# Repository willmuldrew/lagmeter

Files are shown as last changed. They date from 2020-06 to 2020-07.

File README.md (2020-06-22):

Lagmeter
--------

The hardware works by itself and measure total display lag from a simulated HID event to a dark to/from light transition on the screen.  Results are displayed on OLED screen.  The USB bus is pretty fast - events reach your app in ~1-2 ms.  The same cannot be said of all real keyboards which can add 10s of ms through a combination of slow matrix scanning/embedded CPU and slow USB bus polling speeds.

Different test modes can be selected by holding down the button to cycle through keypress (x), alt-tab, alt-esc, mouse click etc...

Optionally, you can run some software on the target machine to collect more data:
 * lagcap.py - captures packets on an interface and pulls light sensor results from arduino. Writes both into csvs in your temp dir.  Syncs clock with device
 * LagWinApp.exe - very minimal windows app that cycles from black-white-black with keypresses (x).  Also logs timestamped WM_PAINT, WM_KEYDOWN events to the tempdir
 * ProcessResults.ipynb jupyter notebook - reads in arduino output, pcap and LagWinApp output from disk and plots some results

Here's some of the charts that the notebook produces showing network traffic for an RDP test.  At the top you see the changing brightness of the screen for a letter X as read by the arduino.  Below you see the network traffic - I can only assume it is the outbound key press and display update coming back - it's all encrypted so you can't really be sure!

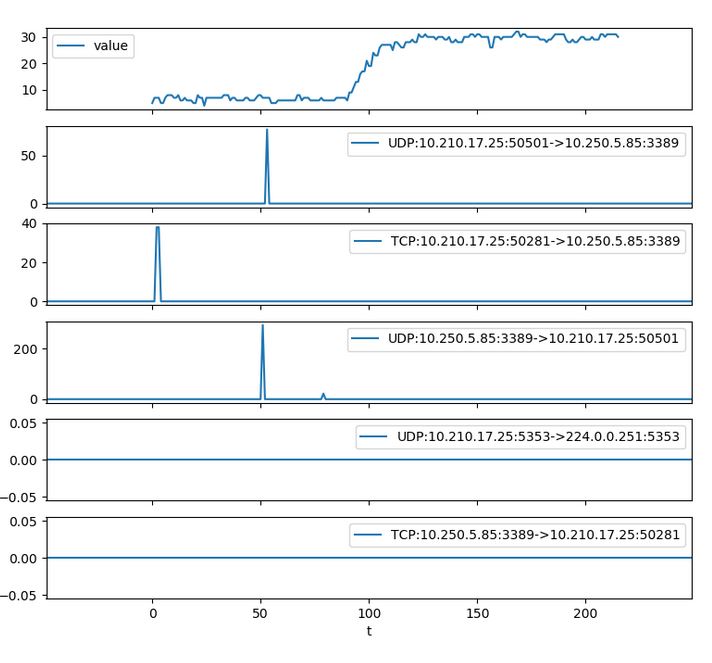
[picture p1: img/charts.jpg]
chart


Getting started
---------------

1. Upload arduino sketch to your Leonardo (or clone)
1. Run lagcap.py locally in a command prompt (e.g. I use a anaconda prompt in a conda environment 
with the relevant deps - pyshark, pyserial, pandas)  Strangely, no admin prompt required despite serial and pcaps
1. Point sensor somewhere on the screen (e.g. just past the cursor on a text prompt - will depend on the selected mode)
1. Hit button
1. Results are written to tmp dir and can be viewed with the ProcessResults jupyter notebook

Building LagWinApp
------------------

If you want a really minimal baseline app you can build and run LagWinApp and use that as your test target. It will drop some timestamped window message logs in the temp dir which can be plotted against other data.

I've build this with Visual Studio 2019 - you can download the community edition for free from MS.

Python Dependencies
------------

pyshark, pyserial and pandas

Hardware
--------

Here's my meter:

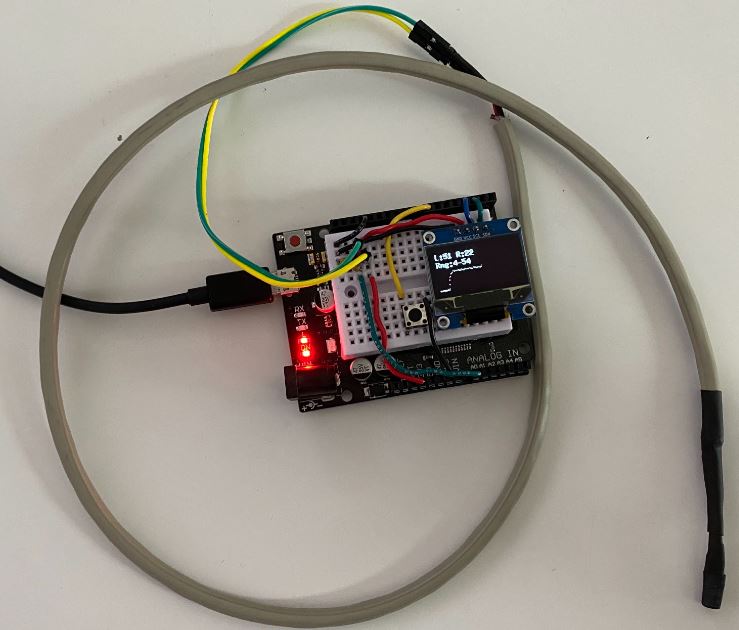
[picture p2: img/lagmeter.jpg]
meter


And here's the wiring (I hope this is right!)  It's not exactly the same I2C SSD 1306 display I use or phototransistor part, but you get the idea. Some notes:
* Leonardo I2C pins are in a different location from other models - check the data sheets
* Make sure you connect the phototransistor the right way round!

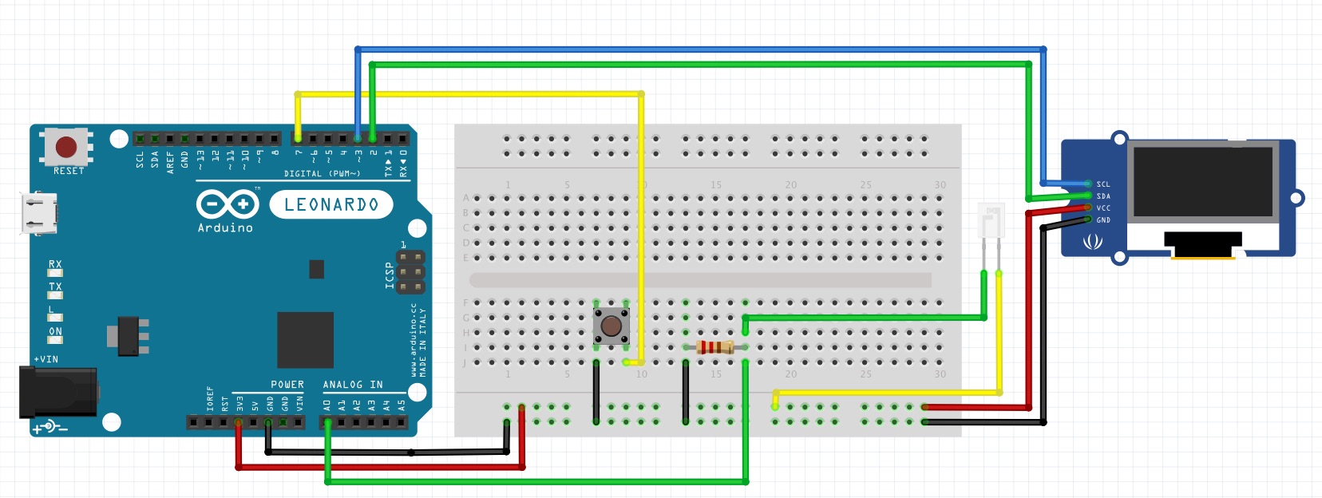
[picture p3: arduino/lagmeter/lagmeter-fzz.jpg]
wiring


Components:
* Arduino Leonard or clone (it's required since it can emulate a USB HID in hardware)
* SSD1306 OLED display - I bought these: https://www.amazon.co.uk/dp/B0832VQN65/ref=pe_3187911_185740111_TE_item
* SFH 3310 phototransistor https://uk.rs-online.com/web/p/phototransistors/6547808/  (I initially used an LDR but it was too slow to react and made it look like the display response time was ~50ms). It's got some heat-shrink round it here for insulation, but also to make a nice window you can point at the screen. Make sure it's wired the right way round!
* momentary microswitch - for initiating captures. Long press to change modes
* resistor 47kohm - this gives us a sensor response time of about 2ms (tested with an led driven by a square wave and an oscilloscope). A smaller resistor means that the capacitance in the sensor drains quicker and response time is faster. However the voltage change shrinks.  2ms seems fine for now, though I might be able to find a better sensor circuit.  I could also use 5v instead of 3.3 (I think), and tweak the software to deal with a lower dynamic range and more noise.
* some wires/cable

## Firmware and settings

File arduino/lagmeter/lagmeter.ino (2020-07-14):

// libs required:
// u8g2 (display)
// AceButton (pushbuttons)


#include <Arduino.h>
#include <Keyboard.h>
#include <Mouse.h>
#include <Wire.h>
#include <U8g2lib.h>
#include <AceButton.h>

using namespace ace_button;

#define SYNC_TIMEOUT_MILLIS 1000

#define SAMPLE_BUFFER_LENGTH 200  // not much memory on arduino!
#define MULTI_RUN_LENGTH 10
#define LED_PIN 13 // going to light this while the capture's active - helpful for debugging and calibration

// OLED display
U8G2_SSD1306_128X64_NONAME_1_HW_I2C u8g2(U8G2_R0, /* reset=*/ U8X8_PIN_NONE);

// Target interval for light capture measurements
const int sampleInterval = 2000; // micros - approx

// How long to busy sample the sensor (then applies mean)
const int sampleDuration = 1000;

typedef struct datapoint {
  uint16_t timestamp;
  uint8_t value;
} datapoint_t;

// Global state for the light-level capture buffer
long t0 = 0;
int writePosition = SAMPLE_BUFFER_LENGTH ;
datapoint_t captureBuffer[SAMPLE_BUFFER_LENGTH];

// OLED display status messages
char msgBufferA[17];
char msgBufferB[17];

AceButton startCaptureButton(7);
AceButton modeButton(6);
AceButton* buttons[] = { 
  &startCaptureButton, 
  &modeButton
};

int runsToDo = 0;
int currentRun = 0;

float multiRunLagSum = 0;
float multiRunLagSumSq = 0;
int multiRunLagCount = 0;


enum class Mode { 
  KeyboardX,
  AltTab,
  LeftClick,
  AltEscape, // AltEscape is next window switching - faster than alt tab (use shift to go back!)
  Count
};

Mode currentMode = Mode::KeyboardX;

void nextMode() {
  currentMode = static_cast<Mode>((static_cast<int>(currentMode) + 1) % static_cast<int>(Mode::Count)); 
  writeScreenMessage("Mode:", getModeDescription(currentMode));
}

const char* getModeDescription(Mode m) {
  switch(m) {
    case Mode::KeyboardX:
      return "Key-X";
    case Mode::AltTab:
      return "Alt-Tab";
    case Mode::LeftClick:
      return "Left Click";    
    case Mode::AltEscape:
      return "Alt-Escape";
  }
}

void handleButtonEvent(AceButton* pButton, uint8_t eventType, uint8_t /*buttonState*/) {
  if(pButton == &startCaptureButton) {
    switch (eventType) {
      case AceButton::kEventClicked:
        startTest(1);
        break;
      case AceButton::kEventLongPressed:
        startTest(MULTI_RUN_LENGTH);
        break;    
    }
  } else if(pButton == &modeButton) {
    switch (eventType) {
       case AceButton::kEventClicked:     
        nextMode();
        break;    
    }
  }
}


void setup() {
  for(auto pButton : buttons) {
    pinMode(pButton->getPin(), INPUT_PULLUP);  
    pButton->setEventHandler(handleButtonEvent);
    ButtonConfig* buttonConfig = pButton->getButtonConfig();
    buttonConfig->setEventHandler(handleButtonEvent);
    buttonConfig->setFeature(ButtonConfig::kFeatureClick);
    buttonConfig->setFeature(ButtonConfig::kFeatureLongPress);
    buttonConfig->setFeature(ButtonConfig::kFeatureSuppressAfterClick);
  }
  
  u8g2.begin();
    
  Serial.begin(115200);  
  Keyboard.begin();
  Mouse.begin();

  clearCaptureBuffer();
  writeScreenMessage("Ready...", "");
  drawScreen();

  pinMode(LED_PIN, OUTPUT);    
  digitalWrite(LED_PIN, LOW);
}

void writeScreenMessage(const char* line1, const char* line2) {
  snprintf(msgBufferA, sizeof(msgBufferA), line1);
  snprintf(msgBufferB, sizeof(msgBufferB), line2);
  drawScreen();   
}

void clearCaptureBuffer() {
   memset(captureBuffer, 0, sizeof(captureBuffer));
}

void drawScreen() {
  u8g2.firstPage();  
  do {
    // Write some messsages
    u8g2.setFont(u8g2_font_7x13B_tf);
    u8g2.drawStr(0,13, msgBufferA);
    u8g2.drawStr(0,26, msgBufferB);

    // Draw a tiny chart
    int nWidth = 72;
    int nHeight = 32;
    int range = 1;

    int minValue = 1024;
    int maxValue = -1;

    for(int n=0;n<SAMPLE_BUFFER_LENGTH;++n) {
      int val = captureBuffer[n].value;
      minValue = min(minValue, val);
      maxValue = max(maxValue, val);
    }    
    
    range = max(maxValue - minValue, 32);        
    for(int x=0;x<nWidth;++x) {
        int nSample = (SAMPLE_BUFFER_LENGTH * x) / nWidth;
        int value = captureBuffer[nSample].value;
        int y = (value - minValue) * 32 / range;
        u8g2.drawPixel(x, 63 - y);
    }
  } while(u8g2.nextPage() );
}


// Read a line from serial up to \n with a timeout
unsigned int serialReadLn(char* buffer, size_t buffLength, int timeoutMillis) {
  unsigned long tStart = millis();  
  unsigned int pos = 0;
  memset(buffer, 0, buffLength);

  while(true) {
    if((millis() - tStart) > timeoutMillis) {
      memset(buffer, 0, buffLength);
      pos = 0;
      break;
    }

    if(Serial.available() > 0) {
      char c = Serial.read();
      if(pos < buffLength) {
        buffer[pos++] = c;
      }
      if(c == '\n') {
        break;
      }    
    }
  }
  return pos;
}

void startCapture() {
  clearCaptureBuffer();
  writePosition = 0; 
  t0 = micros();    
  digitalWrite(LED_PIN, HIGH);
}

// Attempt to sync clock with host on serial bus. Requires relevant lagcap python process to be running
// on the other end...  will wait SYNC_TIMEOUT_MILLIS before giving up to prevent the lack of correct
// host process hanging the arduino
//
// 3 way handshake:
//  * the arduino snaps local micros()
//  * ardunio says SYNC to host
//  * host snaps system time and responds OK
//  * ardunio snaps local micros() again
//  * arduino reports both micros timestamps to host
//
// Host now knows that it's system timestamp lies between the two micros() timestamps.  It can then translate
// ardunio micros() timestamps -> system time with a sub milli accuracy (round-trip is ~0.5ms IIRC)
// 
// Issues:
//  micros() wraps once an hour so could be unlucky... will deal with this at the host end by adding 2**32
//  RTT is variable - could get remote host to respond with AGAIN to retry until a decent RTT is achieved
boolean trySerialClockSync() {
  char strBuffer[64];
  unsigned long localMicrosA = 0;
  unsigned long localMicrosB = 0;

  localMicrosA = micros();
  Serial.print("SYNC\r\n");
  Serial.flush(); 
  
  if(serialReadLn(strBuffer, sizeof(strBuffer), SYNC_TIMEOUT_MILLIS) > 0){      
    if(strcmp(strBuffer, "OK\r\n") == 0) {        
      localMicrosB = micros();
      sprintf(strBuffer, "SYNCED %ld %ld\r\n", localMicrosA, localMicrosB);
      Serial.print(strBuffer);
      Serial.flush();         
      return true;      
    }
  }   
  return false;  
}

boolean isCaptureRunning() {
  return writePosition < SAMPLE_BUFFER_LENGTH;
}

// Take as many readings as possible in the time we're given
int readSmoothedAnalog(int durationMicros){
  unsigned long start = micros();
  unsigned long now = start;
  float sum = 0.0;
  int count = 0;

  // micros() wraps!
  while(now - start < durationMicros && now >= start) {
    sum += analogRead(A0);
    count++;
    now = micros();
  }
  if(count == 0) { 
    // uhoh - either durationMicros was too short, we had a weird hang, or micros wrapped - abort!
    return -1;
  }
  return (int)(sum / count);
}

void startTest(int runs){
  writeScreenMessage("Test", "starting...");  
  if(trySerialClockSync()) {
    delay(1000); // give the remote host a chance to kick off pcaps etc...
  }       

  multiRunLagCount = 0;
  multiRunLagSum = 0;
  multiRunLagSumSq = 0;
  
  runsToDo = runs;
  currentRun = 0;
}

void loop() {  
  if(isCaptureRunning()) {
    // If the capture is running we don't want to do anything else
    unsigned long t = micros();
    int reading = readSmoothedAnalog(sampleDuration);
    if(reading >= 0) {    
      captureBuffer[writePosition].value = reading / 4;
      captureBuffer[writePosition].timestamp = (t - t0) / 1000;
      writePosition++;
    } else {
      // skip - something went a bit wrong!
    }
    
    if(writePosition == SAMPLE_BUFFER_LENGTH) {
      digitalWrite(LED_PIN, LOW); 
      // We've done our last measurement - do some processing for local display and dump results to the 
      // serial port      
      dumpResultsToSerial();
      processResults();
      
      currentRun++;
      if(runsToDo > 1 && currentRun == runsToDo) {
        // We've finished a multirun
        processMultiResults();
      }

      // If we generated a keypress, let's delete it for convenience...  Sometimes it gets annoying though
      // if your backspaces hit a browser!
      doHIDUndo();
      // Update the screen (including drawing a chart)
      drawScreen();      
    } else {
      // busy loop to delay until next sample is scheduled...
      unsigned long now = micros();
      while(now >= t && now < t + sampleInterval) {
        now = micros(); 
      }
    }
  } else if(runsToDo - currentRun > 0){  
    char buff[128];
    sprintf(buff, "run %d/%d", currentRun, runsToDo);
    writeScreenMessage(buff, "");
    if(currentRun > 0) {
      delay(random(500, 2000));
    }
    startCapture();
    doHIDOutput();    
  } else {
    for(auto pButton : buttons) {
      pButton->check();
    }
  }
}

void doHIDOutput() {
  switch(currentMode) {
    case Mode::KeyboardX:
      Keyboard.print("x");
      break;
    case Mode::AltTab:
      Keyboard.press(KEY_LEFT_ALT);
      Keyboard.press(KEY_TAB);
      delay(1);
      Keyboard.releaseAll();        
      break;
    case Mode::LeftClick:
      Mouse.click();
      break;
    case Mode::AltEscape:
      Keyboard.press(KEY_LEFT_ALT);
      Keyboard.press(KEY_ESC);
      delay(1);
      Keyboard.releaseAll();     
  }        
}

void doHIDUndo() {
  delay(500);
  switch(currentMode) {
    case Mode::KeyboardX:
      Keyboard.write(KEY_BACKSPACE);
      break;
    case Mode::AltTab:
      Keyboard.press(KEY_LEFT_ALT);
      Keyboard.press(KEY_TAB);
      delay(1);
      Keyboard.releaseAll(); 
      break;
    case Mode::AltEscape:
      Keyboard.press(KEY_RIGHT_SHIFT);
      Keyboard.press(KEY_LEFT_ALT);
      Keyboard.press(KEY_ESC);
      delay(1);
      Keyboard.releaseAll(); 
  }        
}

void dumpResultsToSerial() {
  // Dump CSV results to serial bus - easy to load into a pandas dataframe
  Serial.println("resultsStart");
  Serial.println("t0,t,value");
  for(int i=0;i<SAMPLE_BUFFER_LENGTH;++i) {
    Serial.print(t0 / 1000);
    Serial.print(",");
    Serial.print(captureBuffer[i].timestamp);
    Serial.print(",");
    Serial.println(captureBuffer[i].value);      
  }
  Serial.println("resultsEnd");
  Serial.flush();
}

int signum(int x) {
  return (x > 0) - (x < 0);
}

void processResults() {
  // use first N samples to establish start, last N to establish end, work out when we crossed the half way mark
  const int samplesToAverage = 10;  
  float startSum = 0, endSum = 0;
  
  for(int n=0;n<samplesToAverage;n++) {
    startSum += captureBuffer[n].value;
    endSum += captureBuffer[SAMPLE_BUFFER_LENGTH - n - 1].value;
  }

  float startMean = startSum / samplesToAverage;
  float endMean = endSum / samplesToAverage;
  int midPoint = (int)(0.5 * startMean + 0.5 * endMean + 0.5);
  int startPoint = (int)(0.9 * startMean + 0.1 * endMean + 0.5);
  int endPoint = (int)(0.1 * startMean + 0.9 * endMean + 0.5);

  int cmpsgn = startMean < endMean ? 1 : -1;
  int midN = -1, startN = -1, endN = -1;
  for(int n=0;n<SAMPLE_BUFFER_LENGTH;++n) {
    int x = captureBuffer[n].value;
    if(midN == -1 && signum(x - midPoint) == cmpsgn) {
      midN = n;
    }
    if(endN == -1 && signum(x - endPoint) == cmpsgn) {
      endN = n;
    }
  }

  // Noise can mean that if our start/end points are too close to the start/end means, then the startPoint can 
  // be breached erroneously.  If we go through the samples backwards, hopefully we won't jump the gun!
  for(int n=SAMPLE_BUFFER_LENGTH-1;n>=0;--n) {
    int x = captureBuffer[n].value;
    if(startN == -1 && signum(startPoint - x) == cmpsgn) {
      startN = n;
    }
  }
  
  if(abs(startMean - endMean) < 10) {    
    sprintf(msgBufferA, "ERR:range low");
    sprintf(msgBufferB, "(%d-%d)", (int)startMean, (int)endMean);
    Serial.println("DEBUG: range low");
  } else if(midN == -1 || startN == -1 || endN == -1) {
    sprintf(msgBufferA, "ERR:crossing");
    sprintf(msgBufferB, "not found");
    Serial.println("DEBUG: crossing not found");
  } else {
    int midTime = captureBuffer[midN].timestamp;
    int responseTime = captureBuffer[endN].timestamp - captureBuffer[startN].timestamp;
    
    sprintf(msgBufferA, "L:%d R:%d", midTime, responseTime);
    sprintf(msgBufferB, "Rng:%d-%d", (int)startMean, (int)endMean);

    multiRunLagCount++;
    multiRunLagSum += midTime;
    multiRunLagSumSq += midTime * midTime;
        
    Serial.println(msgBufferA);
    Serial.println(msgBufferB);    
  }  
}

void processMultiResults() {
  if(multiRunLagCount > 0) {    
    float mean = multiRunLagSum / multiRunLagCount;    
    float stddev = sqrt(multiRunLagSumSq / multiRunLagCount - mean * mean);
  
    sprintf(msgBufferA, "L(m):%d std: %d", (int)(mean + 0.5), (int)(stddev + 0.5));
    sprintf(msgBufferB, "count:%d", multiRunLagCount);  
  } else {
    sprintf(msgBufferA, "no valid");  
    sprintf(msgBufferB, "readings");  
  }
}

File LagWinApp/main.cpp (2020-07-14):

#include <windows.h>
#include <d2d1.h>
#pragma comment(lib, "d2d1")

#include "basewin.h"

#include <vector>

template <class T> void SafeRelease(T **ppT)
{
    if (*ppT)
    {
        (*ppT)->Release();
        *ppT = NULL;
    }
}

class MainWindow : public BaseWindow<MainWindow>
{
    ID2D1Factory            *pFactory;
    ID2D1HwndRenderTarget   *pRenderTarget;
    ID2D1SolidColorBrush    *pBrush;
    ID2D1SolidColorBrush    *pAltBrush;
    
    boolean altColour;
    std::vector<struct WinMsg*> messages;

    HRESULT CreateGraphicsResources();
    void    DiscardGraphicsResources();
    void    OnPaint();

    void MainWindow::clearMessages();
    void MainWindow::dumpMessages();

public:

    MainWindow() : pFactory(NULL), pRenderTarget(NULL), pBrush(NULL), altColour(false)
    {
    }

    PCWSTR  ClassName() const { return L"LagWinApp Window Class"; }
    LRESULT HandleMessage(UINT uMsg, WPARAM wParam, LPARAM lParam);
};


HRESULT MainWindow::CreateGraphicsResources()
{
    HRESULT hr = S_OK;
    if (pRenderTarget == NULL)
    {
        RECT rc;
        GetClientRect(m_hwnd, &rc);

        D2D1_SIZE_U size = D2D1::SizeU(rc.right, rc.bottom);

        hr = pFactory->CreateHwndRenderTarget(
            D2D1::RenderTargetProperties(),
            D2D1::HwndRenderTargetProperties(m_hwnd, size),
            &pRenderTarget);

        if (SUCCEEDED(hr))
        {
            hr = pRenderTarget->CreateSolidColorBrush(D2D1::ColorF(1.0f, 1.0f, 1.0f), &pBrush);
            hr = pRenderTarget->CreateSolidColorBrush(D2D1::ColorF(0, 0, 0), &pAltBrush);
        }
    }
    return hr;
}

void MainWindow::DiscardGraphicsResources()
{
    SafeRelease(&pRenderTarget);
    SafeRelease(&pBrush);
}

void MainWindow::OnPaint()
{
    HRESULT hr = CreateGraphicsResources();
    if (SUCCEEDED(hr))
    {
        PAINTSTRUCT ps;
        BeginPaint(m_hwnd, &ps);
        pRenderTarget->BeginDraw();
        pRenderTarget->Clear(this->altColour ? D2D1::ColorF(D2D1::ColorF::Black) : D2D1::ColorF(D2D1::ColorF::White));
        hr = pRenderTarget->EndDraw();
        if (FAILED(hr) || hr == D2DERR_RECREATE_TARGET)
        {
            DiscardGraphicsResources();
        }
        EndPaint(m_hwnd, &ps);
    }
}

int WINAPI wWinMain(HINSTANCE hInstance, HINSTANCE, PWSTR, int nCmdShow)
{
    MainWindow win;

    if (!win.Create(L"LagWinApp - hit x to toggle black/white", WS_OVERLAPPEDWINDOW))
    {
        return 0;
    }

    ShowWindow(win.Window(), nCmdShow);

    // Run the message loop.

    MSG msg = { };
    while (GetMessage(&msg, NULL, 0, 0))
    {
        TranslateMessage(&msg);
        DispatchMessage(&msg);
    }

    return 0;
}

struct WinMsg {
    int64_t timestampMillis;
    char* message;

    WinMsg(int64_t timestampMillis, char* message) {
        this->timestampMillis = timestampMillis;
        this->message = message;
    }
};

int64_t getUnixTimeMicros() {
    FILETIME now;
    GetSystemTimeAsFileTime(&now);

    const int64_t UNIX_TIME_START = 0x019DB1DED53E8000; //January 1, 1970 (start of Unix epoch) in "ticks"
    const int64_t TICKS_PER_MICRO = 10; //a tick is 100ns

    LARGE_INTEGER li;
    li.LowPart = now.dwLowDateTime;
    li.HighPart = now.dwHighDateTime;

    //Convert ticks since 1/1/1970 into millis
    return (li.QuadPart - UNIX_TIME_START) / TICKS_PER_MICRO;
}

void MainWindow::clearMessages() {
    for (auto msg = messages.begin(); msg != messages.end(); ++msg) {
        delete (*msg);
    }
    messages.clear();
}

void MainWindow::dumpMessages() {
    char tmpBuff[1024];    
    char pathBuff[2048];

    GetTempPathA(1024, tmpBuff);
    snprintf(pathBuff, sizeof(pathBuff), "%s\\lagwinapp_msgs.csv", tmpBuff);

    FILE* f = NULL;        
    if (fopen_s(&f, pathBuff, "w") == 0) {

        fprintf(f, "timestampMicros,msg\r\n");
        for (auto msg = messages.begin(); msg != messages.end(); ++msg) {
            WinMsg* pMsg = (*msg);
            fprintf(f, "%lld,%s\r\n", pMsg->timestampMillis, pMsg->message);
        }

        fclose(f);
        OutputDebugStringA("Written messages to: ");
        OutputDebugStringA(pathBuff);
        OutputDebugStringA("\r\n");
    }
    else 
    {
        OutputDebugStringA("Unable to open file\r\n");
    }
}

LRESULT MainWindow::HandleMessage(UINT uMsg, WPARAM wParam, LPARAM lParam)
{
    switch (uMsg)
    {
    case WM_CREATE:
        if (FAILED(D2D1CreateFactory(
            D2D1_FACTORY_TYPE_SINGLE_THREADED, &pFactory)))
        {
            return -1;  // Fail CreateWindowEx.
        }
        return 0;

    case WM_DESTROY:
        DiscardGraphicsResources();
        SafeRelease(&pFactory);
        PostQuitMessage(0);
        return 0;
    case WM_PAINT:        
        messages.push_back(new WinMsg(getUnixTimeMicros(), "WM_PAINT (pre)"));
        OnPaint();
        messages.push_back(new WinMsg(getUnixTimeMicros(), "WM_PAINT (post)"));        
        return 0;
    case WM_KEYDOWN:
    case WM_LBUTTONDOWN:
        clearMessages();
        messages.push_back(new WinMsg(getUnixTimeMicros(), "WM_KEYDOWN(x)"));
        altColour = !altColour;
        RedrawWindow(m_hwnd, NULL, NULL, RDW_INVALIDATE | RDW_UPDATENOW);
        return 0;
    case WM_KEYUP:
    case WM_LBUTTONUP:
        dumpMessages();
        clearMessages();
    
    }

    return DefWindowProc(m_hwnd, uMsg, wParam, lParam);
}

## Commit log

2020-06-19 companion app to pcap and pull result from arduino to local disk
2020-06-19 write up and hardware wiring
    [lagmeter.fzz]
2020-06-19 getting docs nice
    [lagmeter.fzz]
2020-06-20 remove superfluous debug serial prints
2020-06-20 update to wiring
    [lagmeter.fzz]
2020-06-22 tested resistor response
2020-06-22 more comments around the phototransistor resistor
2020-07-14 toggle on left mouse button, also don't worry if x is the keypressed
2020-07-14 added multi runs (w/ mean and stddev) - long press
    use AceButton library to handle button properly
    use 2 buttons - one to toggle mode, one to initiate test/multitest
